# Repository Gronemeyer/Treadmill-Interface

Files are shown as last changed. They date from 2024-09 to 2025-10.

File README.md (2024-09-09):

# Treadmill-Interface
Interface to treadmill encoder with USB-serial and analog outputs

Provides an interface to a treadmill that uses an incremental encoder to monitor speed and distance.
The speed and distance are calculated at each increment of the encoder. Time, speed, and distance are sent out a serial-USB port. The minimum time between readinsg can be set, as well as the time to wait to set zero speed.
The absolute value of speed is also sent out to an SMA connector as an analog signal. Direction is sent out another SMA connector as a 3.3V digital signal. 
The design utilizes a Teensy 4.0.
The encoder voltage provided is 5 volts.

PCB design done in Eagle
Firmware design in Arduino with Teensy extensions
Processor - Teensy 4.0

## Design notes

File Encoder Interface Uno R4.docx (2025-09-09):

Encoder Interface

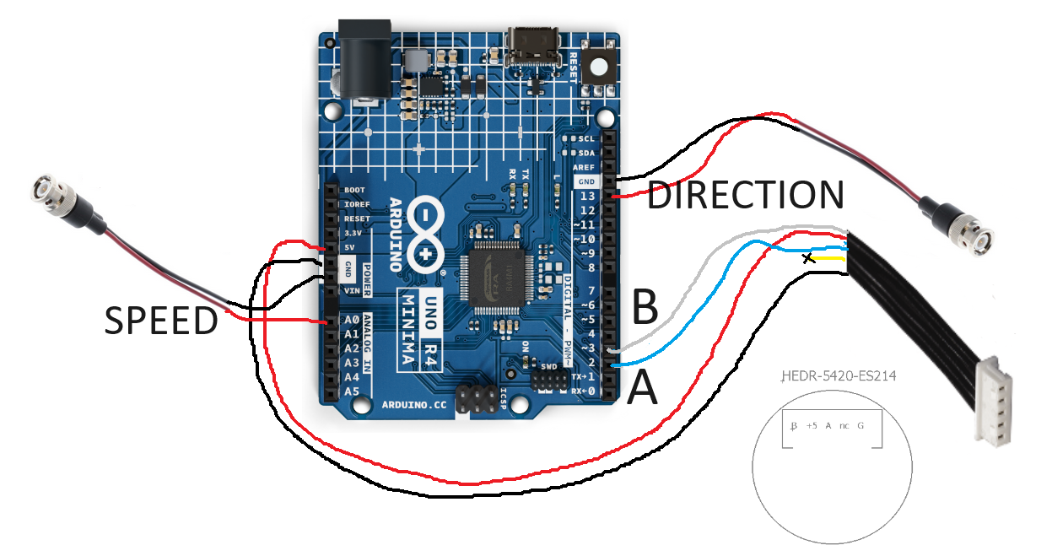
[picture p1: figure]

Steve Sawtelle
Engineer, jET

# System Overview

The Encoder Interface provides a method to connect a quadrature encoder to serial and analog interfaces. The emphasis is on simplicity and ease of assembly. The interface reads the encoder and calculates speed and direction based on time between encoder edge changes using the internal timer on the processor. Speed is updated every time it changes. If no changes are detected over a set time (typically 50 milliseconds) the speed is set to 0. Distance is also accumulated. The USB-serial connection prints the distance and speed every change. The analog output sets a voltage proportional to forward speed (as it is a unipolar output). The calibration of speed, distance, and output voltage can all be customized.

# Hardware Development

A top priority of this design is ease of assembly and programming. No circuit boards need to be made and only basic soldering skills are required. The processor boards are Arduino compatible.

A variety of processor boards are available that can be programmed under Arduino. There is a much smaller subset that is optimal to use for this interface. The requirements of the interface are:

1. 5-volt tolerant inputs, as the encoder is a 5-volt device.
2. Interrupt capability on the inputs.
3. Analog output for speed.
4. Digital-to-Analog Converter (DAC) output for direction.
5. Built-in USB for programming and serial output.

The simplest board to use is probably the Arduino R4 Minima. Other boards could also work, keeping in mind the constraints listed above.

# Assembly

If analog outputs are not needed the BNC cable assemblies can be ignored. Be sure to insulate wires and connections so that no shorts occur. Note: the encoder connector pinout is:

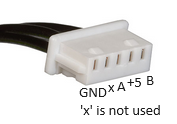
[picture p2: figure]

Arduino R4 Minima

Quantity | Description | Manufacturer | Part Number
1 | Processor | Arduino | UNO R4 MINIMA
2 | BNC connector | Pomonoa | 5069
1 | Cable assembly | Molex | 151340503
1 set | Pin jumper wire assortment | Pololu | 3965
AR | Heat-shrink tubing

The encoder cable assembly has connectors at both ends, so it can be cut in half. The connections to the board are made by soldering each BNC and Encoder cable end to a pin jumper (which have also been cut in half) and covering the connection with heat-shrink tubing. Hot melt glue can be used to help hold the pin connectors in place. The different colored wires shown are simply to make it easy to trace each wire.

# Firmware and Calibration

The firmware was developed under the Arduino environment. The Arduino R4 Board may need to be added to the Board Library.

Various values may need to be modified to suit a particular treadmill setup. The calibration can be checked by moving the treadmill belt a set distance and calculating the difference in the start and end points sent over the serial port. The analog output speed range also be adjusted.

MAXSPEED - the speed (mm/sec) that will cause the maximum voltage output (assuming 0 mm/sec is 0 volts).

SHOW_MICROS – if defined, then the running micros value will be output to the serial port along when new data is sent.

SHOW_REVERSE – if defined, then reverse running will subtract distance (and calculate negative speed).

SPEED_TIMEOUT – Zero speed will be assumed if no encoder interrupts occur within this many microseconds.

SHOW_ZERO – if defined, will output 0 speed after SPEED_TIMEOUT microseconds.

CYCLINDER_8IN – for the 8-inch cylindrical treadmill, extra interrupts are used to get additional resolution in the speed and distance since the treadmill moves further for each encoder count.

Encoder Interface

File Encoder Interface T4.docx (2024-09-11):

Encoder Interface T4

https://github.com/janelia-experimental-technology/Treadmill-Interface

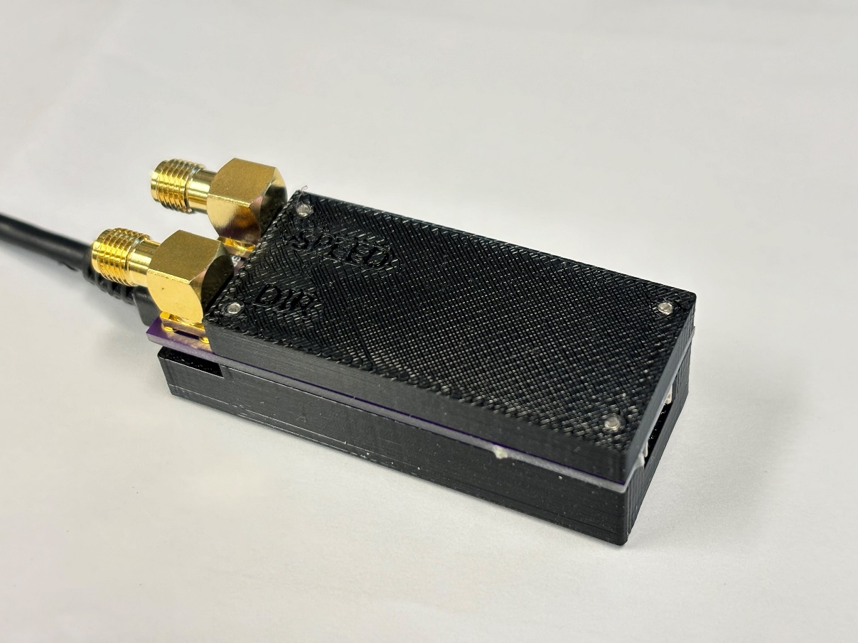
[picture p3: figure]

Steve Sawtelle
Engineer, jET

# System Overview

The Encoder Interface provides a method to connect a quadrature encoder to serial and analog interfaces. The emphasis is on simplicity and ease of assembly. The interface reads the encoder and calculates distance, speed, and direction based on time between encoder edge changes using the internal timer on the processor. These values are updated every time it changes until the updates exceed a selectable maximum update rate. If no changes are detected over a set time (typically 50 milliseconds) the speed is set to 0. The USB-serial connection prints the distance and speed every change. The analog output sets a voltage proportional to absolute speed (as it is a unipolar output), and a digital output provides direction information. The calibration of speed, distance, and output voltage can all be customized.

# Hardware Development

The design is based around a Teensy 4.0 processor. The encoders used in Janelia treadmills require a 5-volt supply, so a level translator is required to interface with the 3.3-volt inputs of the Teensy. The Teensy does not have a standard digital-to-analog converter, so a pulse-width-modulated output is used, along with a low pass filter and buffer amplifier.

The encoder connection is set up to connect to the treadmill encoder using an off-the-shelf cable:

Molex 151315134050X

Note that this cable reverses pinouts at the two ends, so maintain this wiring if building a custom cable.

# Firmware and Calibration

The firmware was developed under the Arduino environment.

Various values may need to be modified to suit a particular treadmill setup. The calibration can be checked by moving the treadmill belt a set distance and calculating the difference in the start and end points sent over the serial port. The analog output speed range also be adjusted. The default values are set to work with the Rodent-Belt-Treadmill:

https://github.com/janelia-experimental-technology/Rodent-Belt-Treadmill

These are the values that can be modified:

SHOW_MICROS – if defined, then the running micros value will be output to the serial port along when new data is sent.

SHOW_REVERSE – if defined, then reverse running will subtract distance (and calculate negative speed).

SPEED_TIMEOUT – Zero speed will be assumed if no encoder interrupts occur within this many microseconds.

SHOW_ZERO – if defined, will output 0 speed after SPEED_TIMEOUT microseconds.

CYCLINDER_8IN – for the 8-inch cylindrical treadmill, extra interrupts are set to get additional resolution in the speed and distance since the treadmill moves further for each encoder count.

UPDATE_USECS – this defines the maximum update rate in microseconds. Without this, at fast treadmill speeds, there may be too many updates for the host computer to keep up with. When this occurs, the average speed is used.

MAXSPEED - the speed (mm/sec) that will cause the maximum voltage output (assuming 0 mm/sec is 0 volts).

Encoder Interface T4

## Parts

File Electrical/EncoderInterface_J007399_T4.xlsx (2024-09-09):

Partlist exported from Z:/ID&F/ENCODER_INTERFACE_T3.2/ECAD/EncoderInterface_J007399_T4.sch at 9/9/2024 12:05 PM
Qty | Value | Device | Designators | Manufacturer | Man PN | Vendor | Vendor PN | $ea | $Total | Notes
2 | SMA | SMA jack, female | DIR SPEED | TE Connectivity Linx | CONSMA002
2 | 0.1 | CAPS0603S | C1 C3 | Kemet | C0603C104K5RACTU
1 | 0.1 NPO | CAPS1206S | C2 | TDK | CGA5L2NP01H104J160AA
1 | 2G17 | IC BUF NON-INVERT 5.5V SOT23-6 | U1 | Texas Instruments | 296-SN74LVC2G17DBVRCT-ND
1 | 10 | CAP CER 10UF 16V X7R 1206 | C4 | Samsung Electro-Mechanics | CL31B106KOHNNWE
1 | 10K0 | RES 10K OHM 1% 1/8W 0805 | R1 | Stackpole Electronics Inc | RMCF0805FT10K0
1 | 53048-05 | CONN HEADER R/A 5POS 1.25MM | J100 | Molex | 530480510
1 | TSV911ILT | General Purpose Amplifier 1 Circuit Rail-to-Rail SOT-23-5 | U2 | STMicroelectronics | TSV911ILT
1 | Header | CONN HEADER VERT 32POS 2.54MM | M1A. M1B | TE Connectivity AMP Connectors | 3-826646-2 |  |  |  |  | Cut AR
1 | Teensy 4.0 | Development Board |  | PJRC | Teensy 4.0

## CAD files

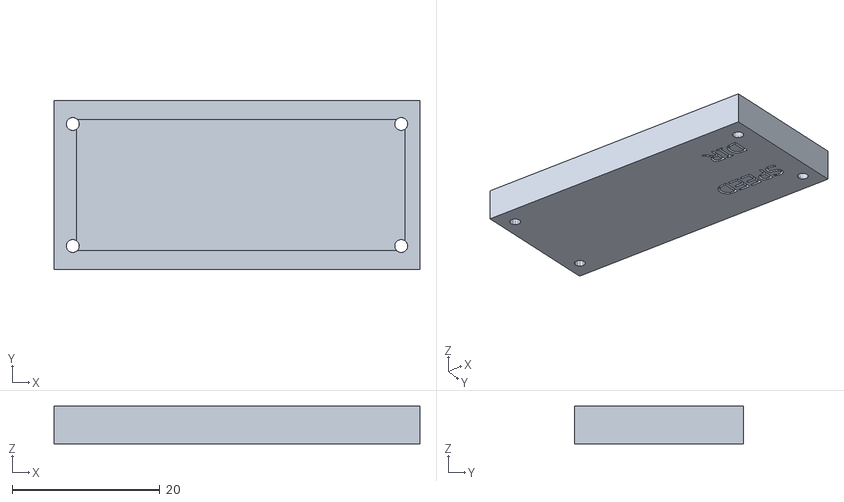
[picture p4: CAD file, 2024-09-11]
MCAD/TreadmillT4bot.stl
49.5 x 22.9 x 5.08

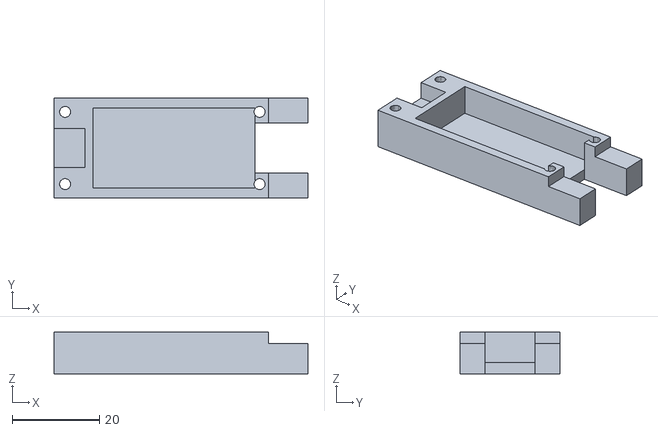
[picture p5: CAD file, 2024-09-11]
MCAD/TreadmillT4top.stl
58.1 x 22.9 x 9.52

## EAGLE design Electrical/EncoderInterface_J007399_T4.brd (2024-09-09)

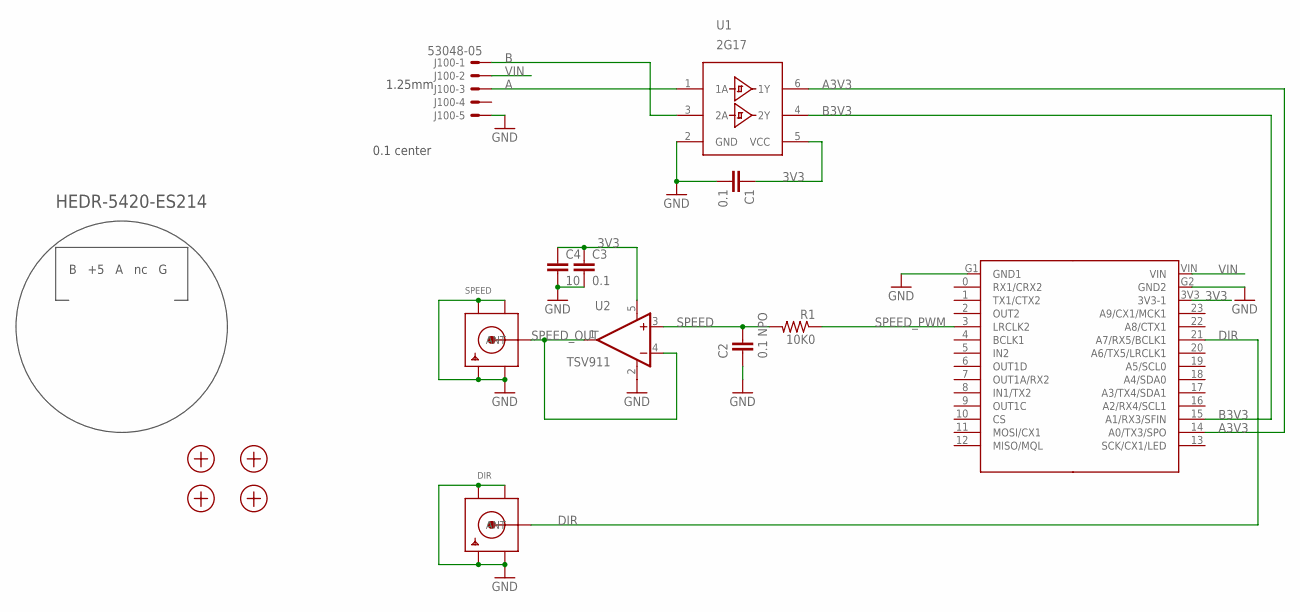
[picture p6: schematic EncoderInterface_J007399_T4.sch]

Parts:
C1, C3: 0.1; 0603S
C2: 0.1 NPO; 1206S
C4: 10; 1206S
DIR: SMACONNECTOR; SMA90_DIP
J100: 53048-05
M1A: TEENSY40A; TEENSY40-A
M1B: TEENSY40B; TEENSY40-B
R1: 10K0; 0805S
S1, S2, S3, S4: SCREW2-56SCREW; 2-56SOCKET
SPEED: SMACONNECTOR; SMA90_DIP
U1: 2G17; SOT23-6
U2: TSV911; SOT23-5

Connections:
3V3: C1.1, C3.1, C4.1, M1B.3V3 (3V3-1), U1.5 (VCC), U2.5 (V+)
A: J100.3, U1.1 (1A)
A3V3: M1B.14 (A0/TX3/SPO), U1.6 (1Y)
B: J100.1, U1.3 (2A)
B3V3: M1B.15 (A1/RX3/SFIN), U1.4 (2Y)
DIR: DIR.ANTENNA (ANT), M1B.21 (A7/RX5/BCLK1)
GND: C1.2, C2.2, C3.2, C4.2, DIR.GND1, DIR.GND2, DIR.GND3, DIR.GND4, J100.5, M1A.G1 (GND1), M1B.G2 (GND2), SPEED.GND1, SPEED.GND2, SPEED.GND3, SPEED.GND4, U1.2 (GND), U2.2 (V-)
SPEED: C2.1, R1.2, U2.3 (+IN)
SPEED_OUT: SPEED.ANTENNA (ANT), U2.1 (OUT), U2.4 (-IN)
SPEED_PWM: M1A.3 (LRCLK2), R1.1
VIN: J100.2, M1B.VIN

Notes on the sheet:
B +5 A nc G
HEDR-5420-ES214
0.1 center
1.25mm

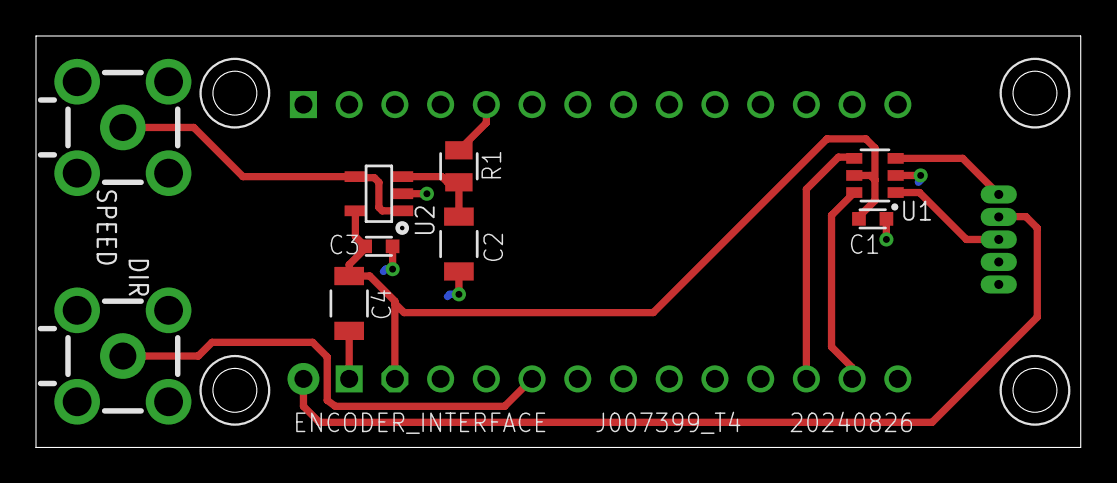
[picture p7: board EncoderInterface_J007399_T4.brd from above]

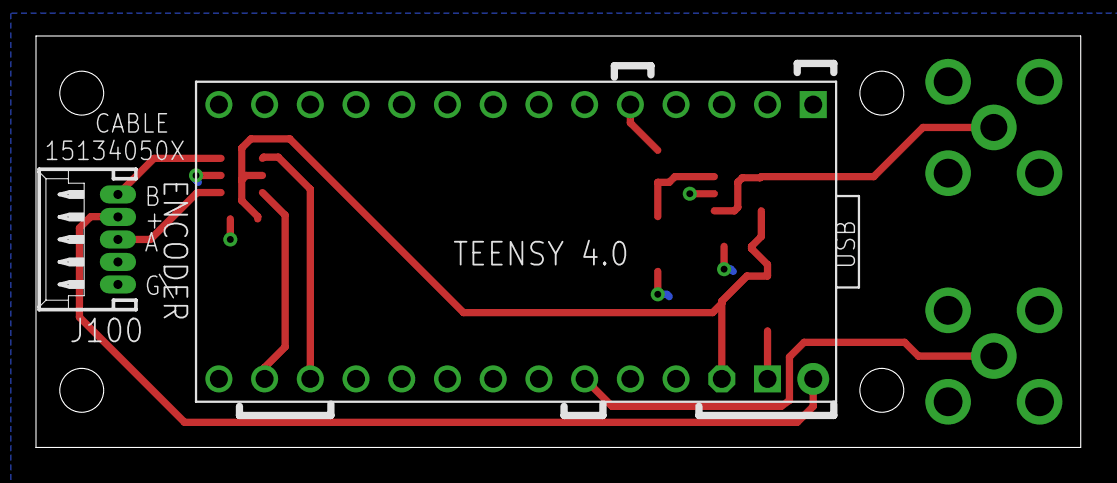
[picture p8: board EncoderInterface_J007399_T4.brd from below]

Board: 2 copper layers, 58.0 x 22.9 mm, 16 parts (3 on the bottom side), 11 nets.

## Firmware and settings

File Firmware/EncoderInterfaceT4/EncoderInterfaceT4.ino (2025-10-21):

 // EncoderInterfaceT4
//
//  Read the encoder and translate to a distance and send over USB-Serial and PWM DAC
//  Teensy 4.0 with Teensy Extensions

//  Encoder A - pin 14
//  Encoder B - pin 15
//  Encoder VCC - Vin
//  Encoder ground - GND
//  PWM Analog Out - pin 3
//  Direction pin - pin 21
//
// Steve Sawtelle
// jET
// Janelia
// HHMI 
//

#define SHOW_MICROS    // if defined, print micros() with each output
#define SHOW_REVERSE   // if this is defined, show abs value of speed, else ignore reverse distance/speed
#define SHOW_ZERO      // if this is defined, show 0 speed if no movement in SPEED_TIMEOUT micros
//#define CYLINDER_8IN   // if this is defined, will compile for 8" cyclinder, else standard belt 

//#define ZERO_OFFSET    // if this is defined, offset zero to 1/2 Max DAC to allow sending reverse speed through DAC
//                          if used must also define SHOW_REVERSE

#define UPDATE_USECS 20000  // don't print faster than this many micros
#define SPEED_TIMEOUT 100000  // if we don't move in this many micros assume we are stopped and show 0.0 speed 


#define VERSION "20240909"
// ===== VERSIONS ======

// 20240909 sws
// - from EncoderInterfaceT3, changes to use Teensy 4.0
//   pin changes
//   add in spped and dir outputs, speed is PWM analog

// 20230621 sws
// - add ability to compile for cylinder treadmill

// 20230523 sws
// - remove debug output in loop
// - add '?' query for version

// 20220419 sws
// - update lastUsecs during zero speed time so that when the treadmill starts again the speed 
//   is based on the end of last zero time out

// 20221212 sws from suggestions by york at Labmaker
// - strict even intervals causes poor low speed granularity
// - so, return to incremental updates, but limit to no faster than UPDATE_USECS 
// - make define to allow showing zero if no movement in SPEED_TIMEOUT micros
// - add define to allow printing of micros() value

// 20221017 sws
// - add define to print distance and speed at even intervals. 
//     To use allow #define TIMED_UPDATE and UPDATE_RATE sets the rate in updates per second

// 20220720 sws
// - also need to use pin 3 not 0 in LC as 0 doesn't have interrupt capability
// - to keep backward compatibility, set the unused pin as input so they can be tied
//    together on PCB

// 20220711 sws
// - provide alternate compile for Teensy LC, A12 not A14 for DAC

// 20211109 sws
// - was printing absolute run speed, now it shows as negative if reverse

// 20211021 sws
// - add define for offsetting DAC to show reverse speed 

// 20180514 sws
// - DIR pin was set to 12 but hardware has it on 2
// - also had index pin as 2 should be 14

// 20180328 sws
// - remove wait for serial since it will not move past it if no serial port is defined

// 20180319 sws
// - add define to allow showing reverse direction

#define MAXSPEED    1000.0f  // maximum speed for dac out (mm/sec)
#define MAXDACVOLTS 2.5f    // DAC ouput voltage at maximum speed
#define MAXDACCNTS  4095.0f // maximum dac value - should be 2^(analogWriteResolution)

float maxDACval = MAXDACVOLTS * MAXDACCNTS / 3.3; // limit dac output to max allowed

#define speedPin 3    
#define encAPin 14 // 12
#define encBPin 15 // 11
#define dirPin 21    // 0 = forward,1 = reverse


#ifdef CYLINDER_8IN
// counts per rotation of cylindrical treadmill encoder wheel: 200 counts per rev, 7.90" per rev (was 7.95)
// so - 7.90 * 25.4 * pi / 200  = microns/cnt
// when using rising and falling edges of both channels, must divide by 800
// first version of cylinder used /200 and then /4 in distance per count, but the /4 should be here
#define MM_PER_COUNT 787990  // 3171909  // actually 1/10^6mm per count since we divide by usecs
#else
// counts per rotation of treadmill encoder wheel
// 200 counts per rev
// 1.03" per rev
// so - 1.03 * 25.4 * pi / 200 /1000 = microns/cnt
#define MM_PER_COUNT 410950  // actually 1/10^6mm per count since we divide by usecs
#endif

#define DIST_PER_COUNT ((float)MM_PER_COUNT/1000000.0)   //(float)0.41095
 
#define SPEED_TIMEOUT 100000  // if we don't move in this many microseconds assume we are stopped

static float runSpeed = 0;
static float lastSpeed = 0;
volatile uint32_t lastUsecs;
volatile uint32_t thisUsecs;
volatile uint32_t encoderUsecs;
volatile float distance = 0;
volatile float deltaDistance = 0;
volatile int8_t encoderCounts = 0;

static uint64_t monoUsecs = 0;  // 64-bit monotonic microseconds

#define FW 1
#define BW -1

int dir = FW;

float lastDistance;
float zeroDistance;
volatile boolean movement = false;

// ------------------------------------------
// interrupt routine for ENCODER_A rising edge (and falling if cylinder)
// ---------------------------------------------
void encoderInt()
{   
   thisUsecs = micros();
  
  int ENCA = digitalReadFast(encAPin);  // always update output 
  int ENCB = digitalReadFast(encBPin); 
  // figure out the direction  
    
  if (ENCA == ENCB )  // if same, then backwards
  {   
    dir = BW;
    #ifdef SHOW_REVERSE 
        distance -= DIST_PER_COUNT;
    #endif
  }  
  else
  {
      dir = FW;
      distance += DIST_PER_COUNT;
  }  
   
  #ifndef SHOW_REVERSE   // if not showing reverse speed force reverse to 0
    if( dir == BW ) runSpeed = 0;      
  #endif  

   movement = true;  
     
}


// ------------------------------------------
// interrupt routine for ENCODER_B rising/falling edge - for 8" cylinder
// ---------------------------------------------
void encoderBInt()
{   
   thisUsecs = micros();
  
  int ENCA = digitalReadFast(encAPin);  // always update output 
  int ENCB = digitalReadFast(encBPin); 
  // figure out the direction  
    
  if (ENCA != ENCB )  // if same, then backwards
  {   
    dir = BW;
    #ifdef SHOW_REVERSE 
        distance -= DIST_PER_COUNT;
    #endif
  }  
  else
  {
      dir = FW;
      distance += DIST_PER_COUNT;
  }  
   
  #ifndef SHOW_REVERSE   // if not showing reverse speed force reverse to 0
    if( dir == BW ) runSpeed = 0;      
  #endif  

   movement = true;  
     
}

void setDACspeed(float speed)
{
    float dacval = abs(speed)/MAXSPEED * maxDACval; 
    if( dacval < 0 ) dacval = 0;             
    if( dacval > maxDACval) dacval = maxDACval; 

    analogWrite(speedPin,(uint16_t) dacval);
       
    if( runSpeed < 0 ) 
       digitalWrite(dirPin, HIGH); // and note reverse dir 
    else
       digitalWrite(dirPin, LOW);  // else note forward
}
       

void setup()
{

  Serial.begin(192000);
  // while( !Serial);  // if no USB serial connection, this will hang the program
  
  pinMode(encAPin, INPUT_PULLUP); // sets the digital pin as input
  pinMode(encBPin, INPUT_PULLUP); // sets the digital pin as input
  pinMode(dirPin, OUTPUT);
  digitalWrite(dirPin, LOW);  //  assume forward
  
  analogWriteFrequency(speedPin, 36621.09);  // optimal freq for 12 bit PWM
  // https://www.pjrc.com/teensy/td_pulse.html
  analogWriteResolution(12);

  lastUsecs = micros();
  thisUsecs = lastUsecs;
  lastDistance = 0;
  zeroDistance = 0;
  #ifdef CYLINDER_8IN
    attachInterrupt(encAPin, encoderInt, CHANGE); // check encoder every A pin edge
    attachInterrupt(encBPin, encoderBInt, CHANGE); // check encoder every B pin edge
  #else
    attachInterrupt(encAPin, encoderInt, RISING); // check encoder every A pin rising edge
  #endif  
}

boolean moved = false;

 void loop() 
{  

  if( Serial.available() )
  {
     int8_t charin = Serial.read();
     if ( charin == '?' )
     {
       Serial.print("Treadmill V:");
       Serial.println(VERSION);
       #ifdef CYLINDER_8IN
          Serial.println("8in Cylindrical Treadmill");
       #endif   
       #ifdef SHOW_MICROS 
          Serial.print("micros,");
       #endif
       Serial.println("distance (mm),speed (mm/s)");     
     } 
     else if ( charin == 'c' )
     {
        Serial.print("Speed output calibrate, 0 to ");
        Serial.print(MAXSPEED);
        Serial.println(" mm/sec");
        for( float speed = 0; speed <= MAXSPEED; speed += MAXSPEED/5)
        {
           setDACspeed(speed);
           Serial.println(speed);
           delay(5000);
        }  
      //  setDACspeed(0);   
     }
  }
  
  noInterrupts();
  uint32_t newUsecs = thisUsecs;
  float cumDistance = distance;
  moved = movement;
  movement = false;
  interrupts();
  
  if( (moved) && ((newUsecs - lastUsecs) > UPDATE_USECS ) ) // are we at least past max update rate
  {
    uint32_t usecs = (uint32_t)(newUsecs - lastUsecs);   // unsigned delta handles wrap
    monoUsecs += usecs;
    lastUsecs = newUsecs;
    runSpeed = (1e6f * (cumDistance - lastDistance)) / (float)usecs;
   
  #ifndef SHOW_REVERSE 
     if( (cumDistance - lastDistance) > 0 )
  #endif     
     { 
       // Print monotonic time instead of raw micros() to avoid rollover
       #ifdef SHOW_MICROS     
         Serial.print((unsigned long long)monoUsecs);   
         Serial.print(","); 
       #endif     
       Serial.print(cumDistance);
       Serial.print(",");
       Serial.println( runSpeed); 
            
       lastDistance = cumDistance;

       setDACspeed(runSpeed);
     }
     
  }
  #ifdef SHOW_ZERO
  else 
  {
     uint32_t zeroUsecs = micros();
     if( (uint32_t) (zeroUsecs - lastUsecs) > SPEED_TIMEOUT )
     {
        uint32_t dz = (uint32_t)(zeroUsecs - lastUsecs);
        monoUsecs += dz;
        lastUsecs = zeroUsecs;
      
       if( lastDistance != zeroDistance )
       {
         #ifdef SHOW_MICROS        
           Serial.print((unsigned long long)monoUsecs); //print monotonic time
           Serial.print(",");           
         #endif         
         Serial.print(lastDistance);
         Serial.println(",0.0");  
           
         zeroDistance = lastDistance;
       }  
       
       lastUsecs = zeroUsecs;  // update to most recent time so next speed reading is right
     }   
  } 
  #endif 


} // end loop

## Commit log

2024-09-11 add Housing STL files
    [TreadmillT4bot.stl, TreadmillT4top.stl]
2024-09-11 Add gerbers for PCB
2024-09-11 Move STLs to MCAD folder and add calibration command to FW
    [TreadmillT4bot.stl, TreadmillT4top.stl]
2024-09-11 Create Encoder Interface T4.docx
2025-10-17 Fix: Avoid timestamp 32-bit micros rollover with monotonic microseconds tracking
    Added a 64-bit monotonic microseconds variable and updated calculations to use it for speed and distance tracking.
    [EncoderInterfaceT4.ino]
2025-10-21 Refactor speed calculation and improve time handling
    Updated speed calculation to use monotonic time and fixed type casting.
    [EncoderInterfaceT4.ino]

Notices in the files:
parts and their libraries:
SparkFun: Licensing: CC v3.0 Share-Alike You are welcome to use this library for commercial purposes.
